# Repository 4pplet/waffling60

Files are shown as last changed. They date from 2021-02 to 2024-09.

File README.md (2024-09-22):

# waffling60

waffling60 is a multilayout 60% PCB with support for common ANSI and ISO layouts and split space. The PCB is split into different versions:
- ALPS tray mount version. Fit o-ring gummy worm if USB-port is not populated.
- MX tray mount version. Fit o-ring gummy worm if USB-port is not populated.
- MX Hot swap tray mount PCB in ISO layout. Fit o-ring gummy worm if USB-port is not populated.
- MX Hot swap tray mount PCB in ANSI layout. Fit o-ring gummy worm if USB-port is not populated.
- NMB Space Invader version. Fit o-ring gummy worm if USB-port is not populated.
- A dedicated version of the MX solder PCB to fit bakeneko/Kei cases. For use in Kei cases, a shorter or more flexible daughter board cable is recommended due to a slight different connector placement on PCB.
- A dedicated version of the MX solder PCB to fit ai03 Polaris V1.

Note: Waffling60 ISO HS Rev E is still being verified and added to QMK and VIA. At the moment, use revision D files for manufacturing. When tested and added, I'll change the releases from pre-release to release.

## Features:
- QMK & VIA
- USB-C
- RGB-led under to capslock-switch for non-hotswap and NMB versions. A transparent switch is needed to see the light from the LED through the switch.
- 16 underglow LEDs
- Cherry PCB-stab support
- Split space
- USB horizontal placement is classic GH60, same as GH60, plain60, voyager60 etc for the tray mount versions.
- SE-version is adapted for Polaris (stab-rotations, outline and USB-placement), make sure to order 1.2 mm thickness when manufacturing these.
- Rotary encoder support on top row, furthest to the right. Split backspace position. Only specific SMD encoders fit. Example further down.

## **Disclaimer/note:**
- **Important:** SE version of waffling60 (Polaris compatible version) are not officially endorsed by ai03 and ai03 takes no responsibility or offers any support for these if there is any issue. I have been given permission to open source and offer these for sale.**

## Availability:
As an option to DIY, I'll try and keep these available for purchase here: https://4pplet.com/ For DIY, the production files are avaliable in releases.

## Layout support MX: 
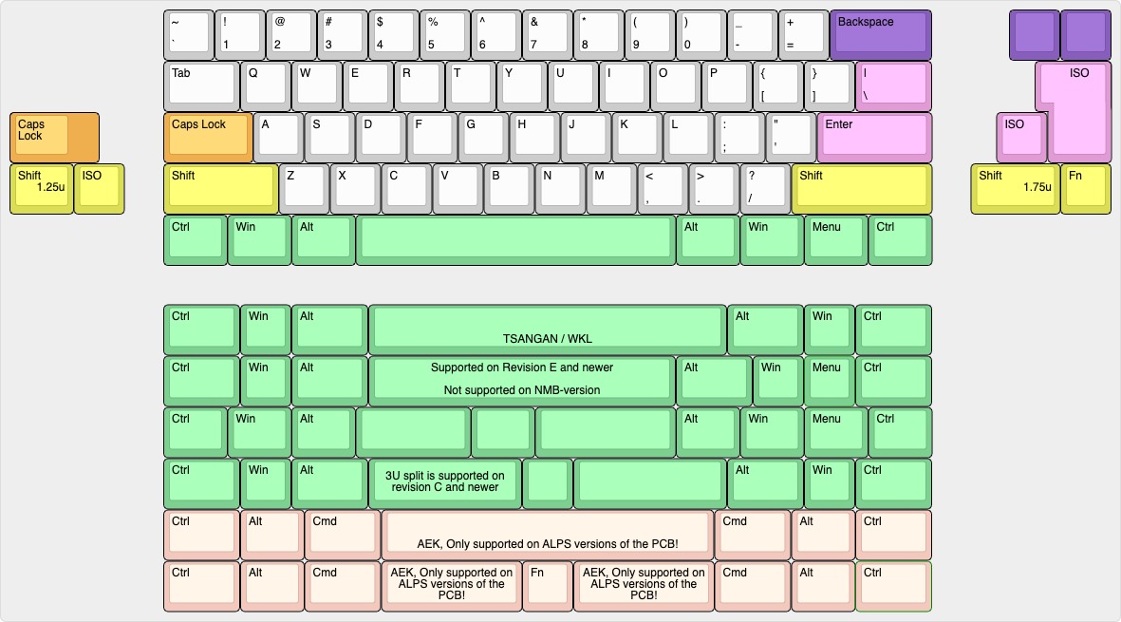
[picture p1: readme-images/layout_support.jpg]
Layout support


## MX Solder
PCB View - Rev E

## ALPS Solder
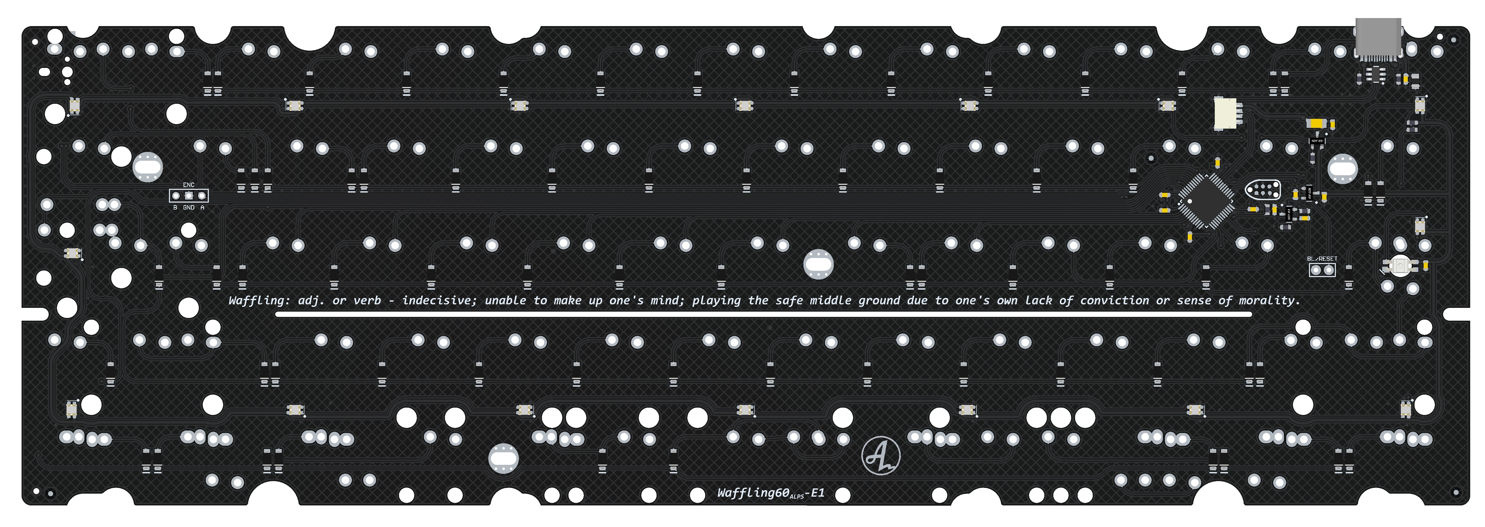
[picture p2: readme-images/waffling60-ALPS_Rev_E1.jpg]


## SE ("Bolaris")
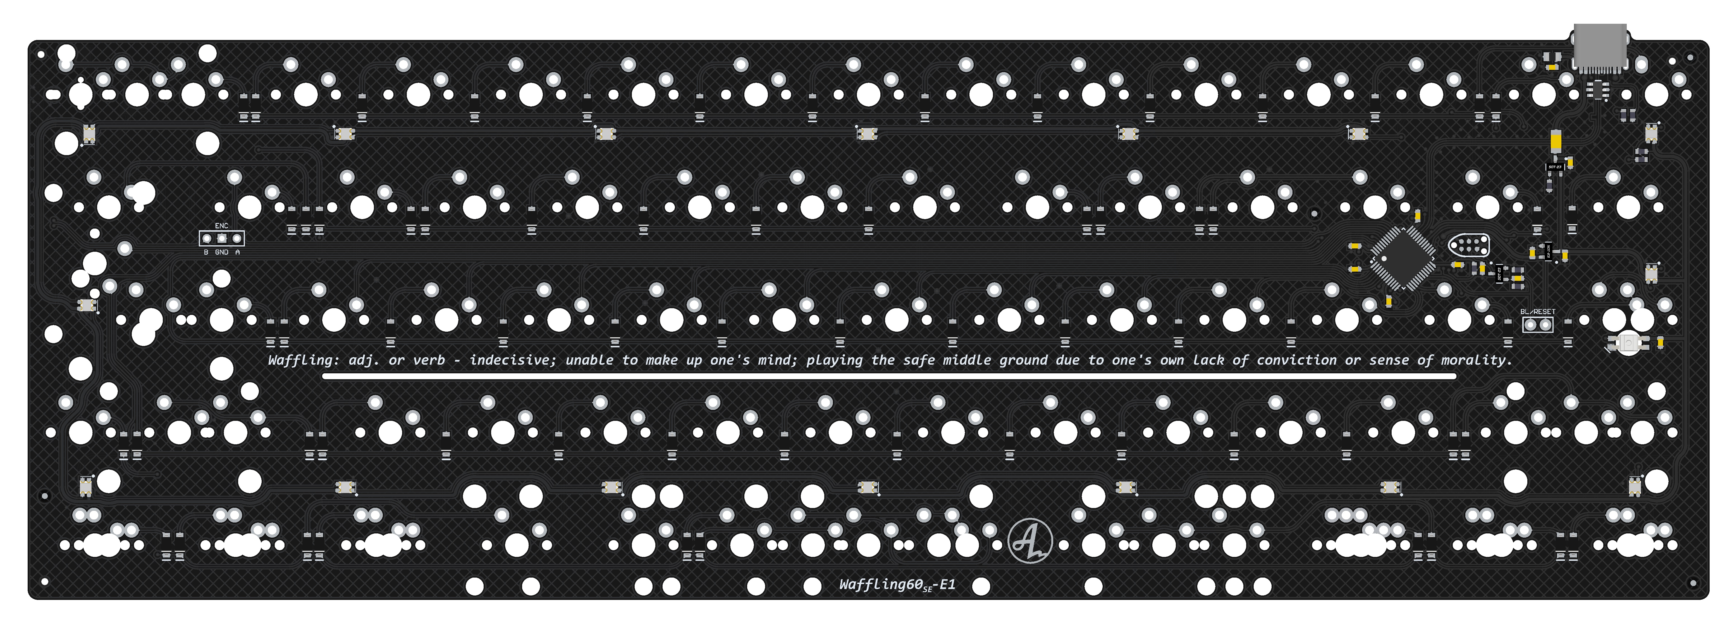
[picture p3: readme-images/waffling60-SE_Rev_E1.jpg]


## DB (Daughterboard/"Bakeneko")
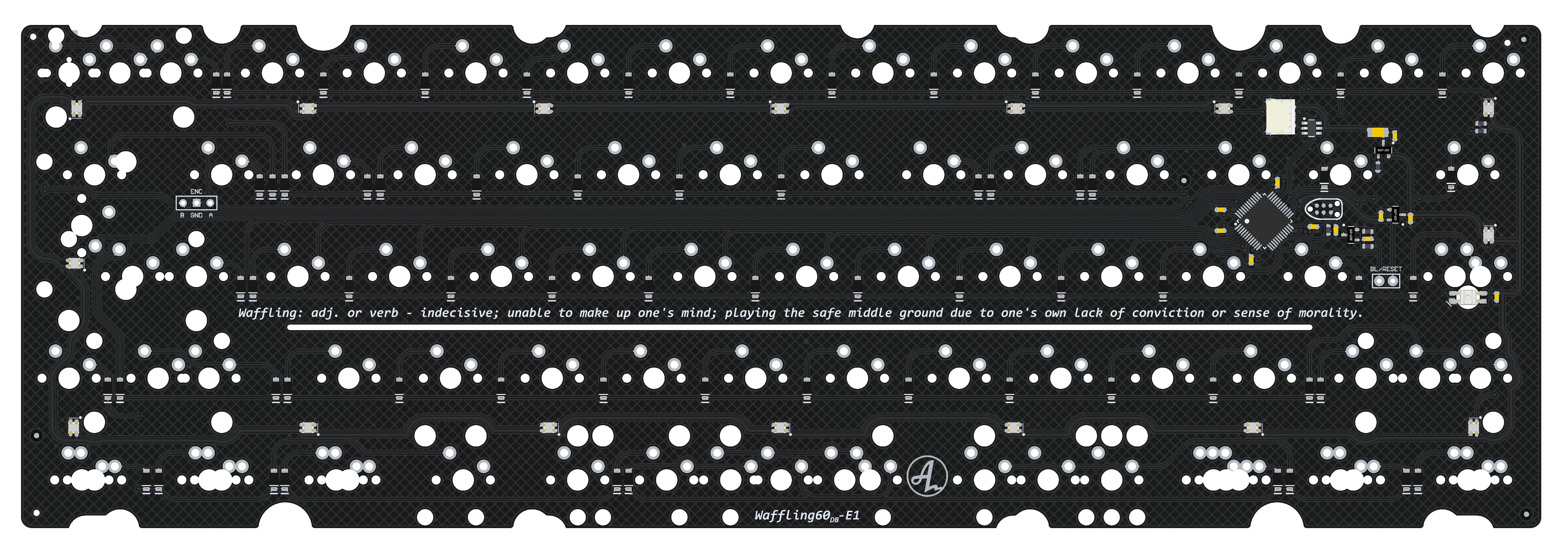
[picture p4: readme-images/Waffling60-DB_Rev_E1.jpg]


## NMB (NMB/Space Invaders)
PCB View - Rev E

## Layout support MX HS ISO: 
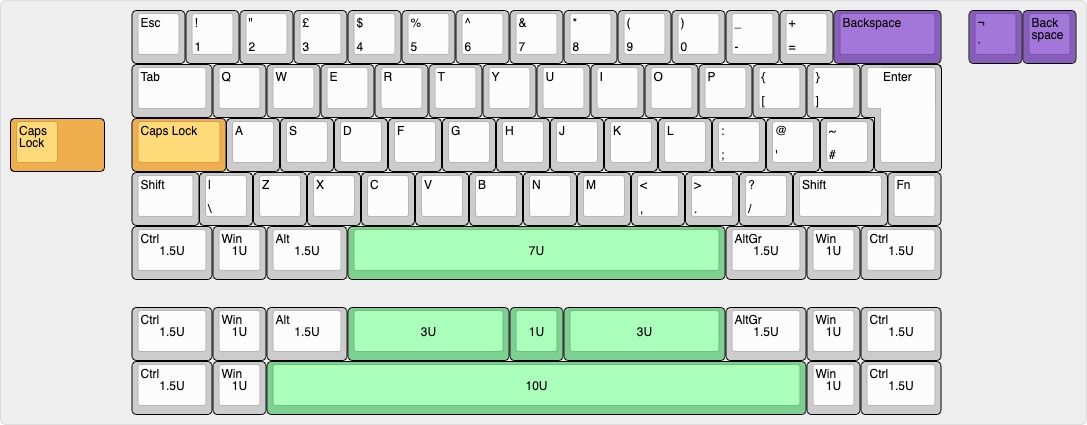
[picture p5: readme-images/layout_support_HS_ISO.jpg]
Layout support


## MX Hot Swap ISO
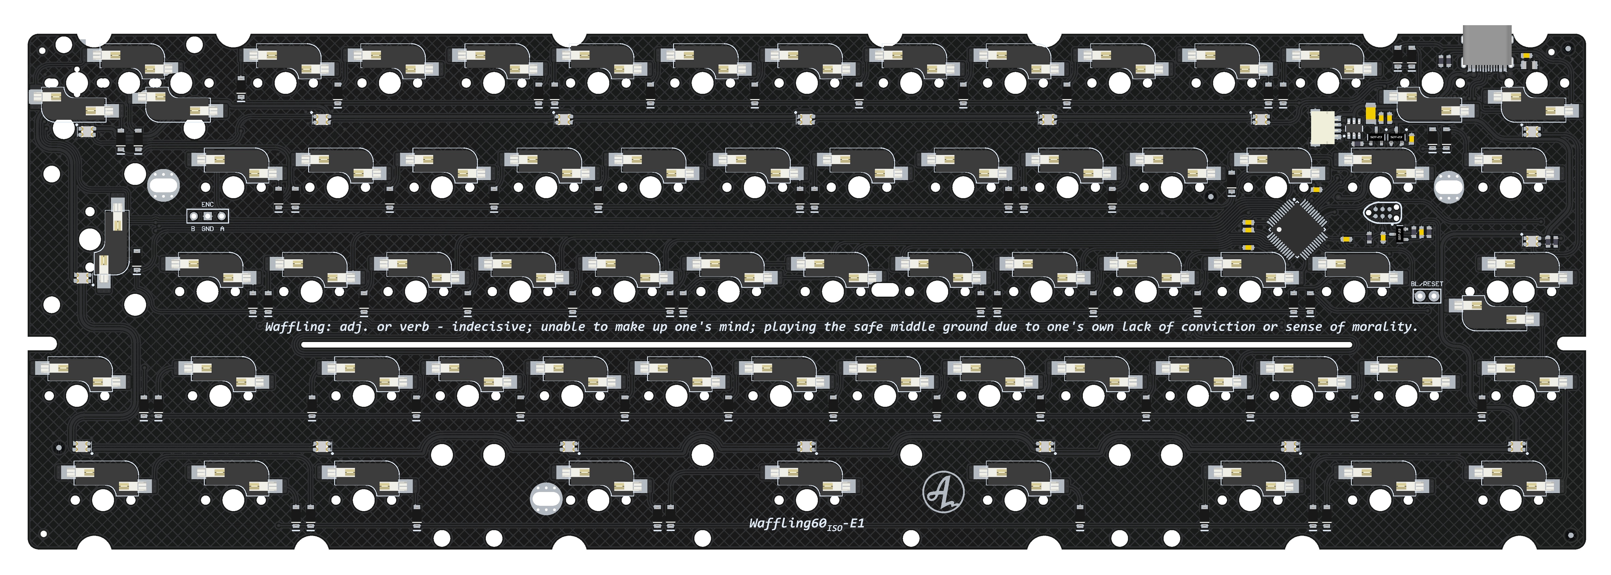
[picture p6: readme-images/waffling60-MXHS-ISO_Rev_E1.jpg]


## Layout support MX HS ANSI: 
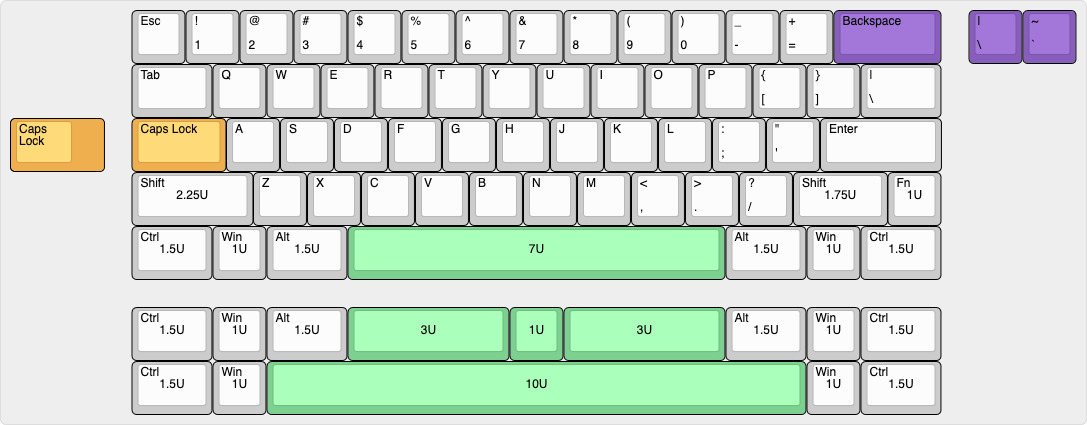
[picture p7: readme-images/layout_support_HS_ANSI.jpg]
Layout support


## MX Hot Swap ANSI
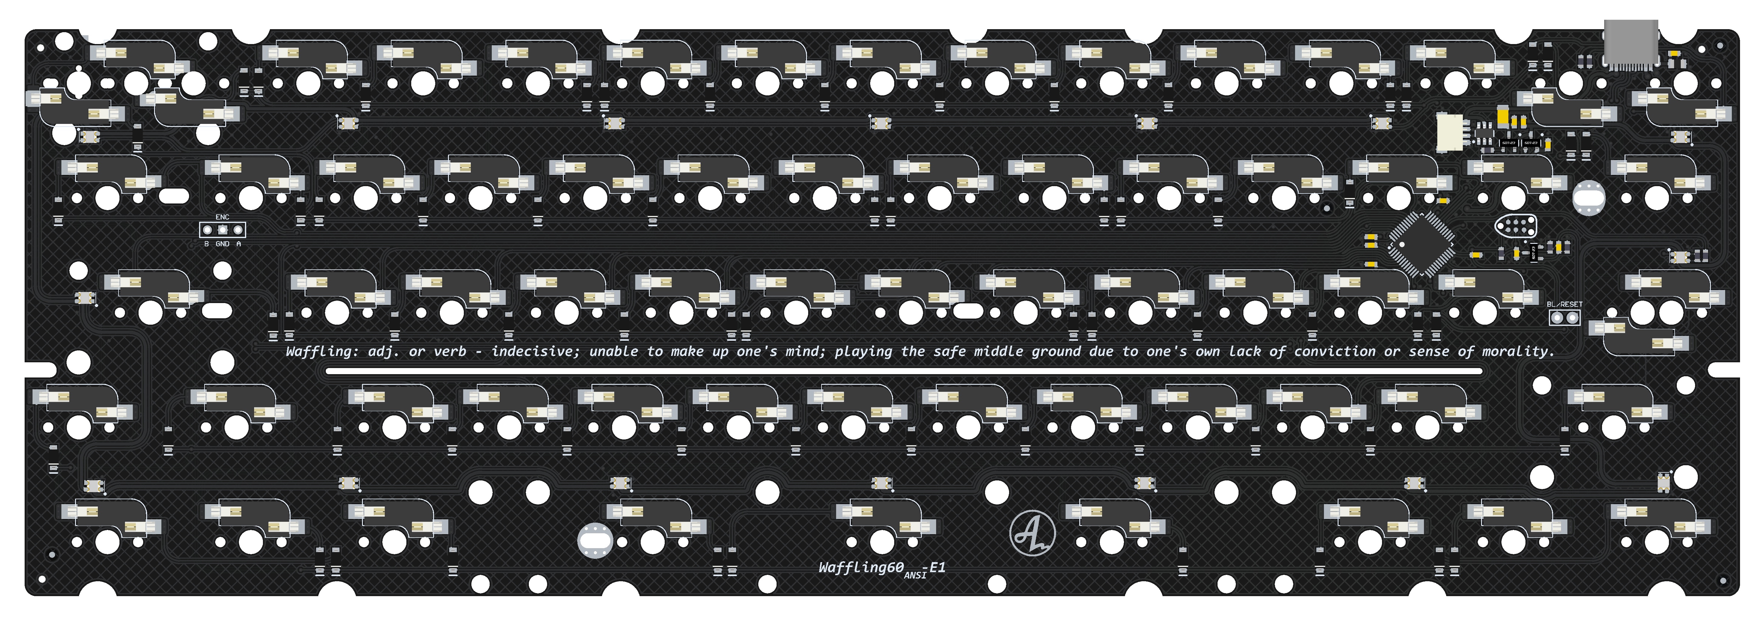
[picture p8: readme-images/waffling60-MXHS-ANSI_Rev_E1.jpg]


## Deviations on NMB version due to switch/footprint constraints:
- Different x-axis JST position, further from the PCB center.
- No Rotary encoder on PCB
- No 6U support
- Different encoder header position for off PCB encoder
- Different JTAG tagconnect position

## Instructions for manufacturing.
All PCBs except for the SE-version ("Bolaris") can be assembled for use with a bakeneko-style case. Simply remove the USB-port from the BOM or de-select it/tell the manu not to assemble it. The process will vary depending on what manufacturer is used.

## For ordering:
The following files are needed for the PCB Fab:
- BOM (contains component specifications)
- Pick and Place (contains component placement data)
- Gerber (contains PCB drawings and drill files)

## Releases
Files for manufacturing can be found in releases: https://github.com/4pplet/waffling60/releases

## Revision naming scheme
- Revision: When updating the PCB I bump the revision. The revision is specified with a letter and a number. For big changes, the letter is changed (usually also include code changes), for minor changes, only the number is bumped.
- Version: Version specifies different switch types, PCB's specific to certain cases etc.

## Revision history:
- Rev A1: Initial prototype based on Steezy60 Alps-version.
- Rev A2: Rotate Fn-switch (split RShift) on solder version. Rotate LShift stabilizer on both versions. To rotate left shift stabilizer on hot-swap pcb, adjacent sockets is also rotated.
- Rev B1: Changed matrix and diode under capslock for cleaner routing and easier software implementation in QMK for LED
- Rev B2: Moved daughter board connector to allign all projects with a similar horisontal position and a identical vertical position. Removed flex-cuts for more preictable feel in "traditional" cases.
- Rev B3: Changed stab rotation to what's more common today. Alligns with most common projects and cases. Updated PCB outline. Moved daughter board connector for better position in bakeneko. Added flexcuts again, but a simpler one.
- Rev B4: Changes to PCB outline, added support for bakeneko V3 and possibly KEI
- Rev B5 - Alps: Adding symetrical split space support using AEK-keycaps and adding RGB led below capslock switch for use with transparent switches (matias)
- Rev C1: Revision adds 3u+1U+3U Split space and 10U space support.
- Rev D: Moves to APM32 MCU, minor changes to routing and USB shielding.
- Rev E1: Adds NMB version. Adds underglow, rotary encoder support and 6u space support. Changed the switch rotation on MX ISO-enter. Reset button removed to reduce risk of resetting the board when bottoming out or when using a lot of foam.
- Rev E2: Fixes missing underglow resistor on NMB PCB. Fixes incorrect 6u support on solder PCBs (all versions with 6u support).
- Rev E3 on Waffling60SE: Adds a missing 5-pin switch hole on bottom row.
- Rev E3 on Waffling60DB: Adjusting UDB connector to align with the rest of the project. It had a slight offset.

## Encoders:
The footprint for encoders is a fairly common one. It supports two versions of bottom pins. The one below is an example. Similar looking SMD encoders (pin placement and bottom pins) will likely fit.

Example of tested encoders:

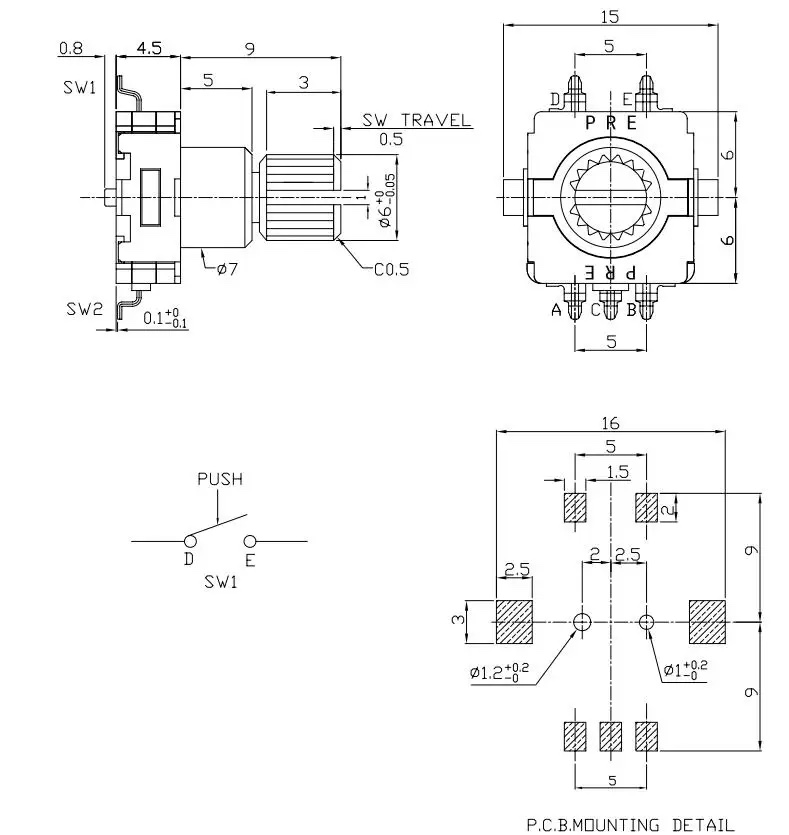
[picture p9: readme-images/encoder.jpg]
Aliexpress Encoder


Link: https://www.aliexpress.com/item/1005001265188249.html

<a href='https://ko-fi.com/4pplet' target='_blank'>Buy Me a Coffee at ko-fi.com

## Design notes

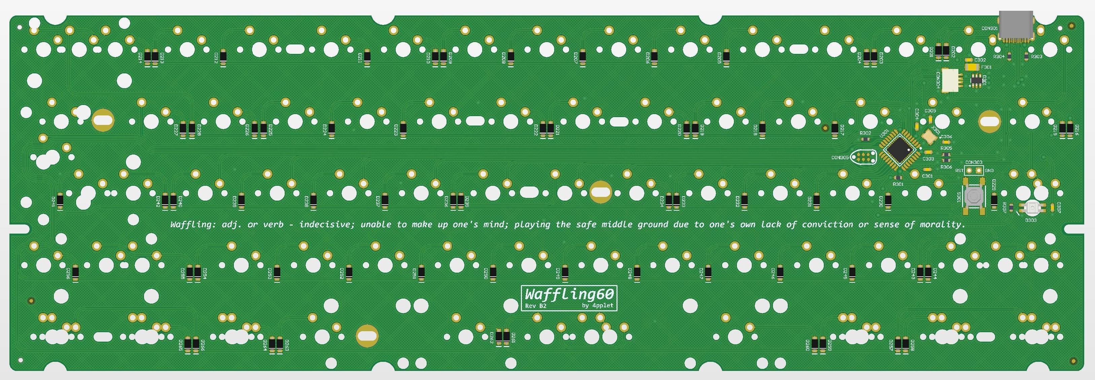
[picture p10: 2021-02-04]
readme-images/waffling60-MX_Rev_B2.jpg

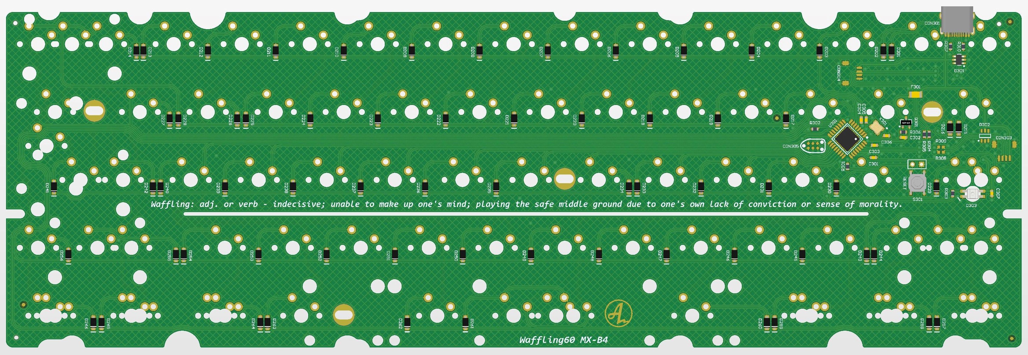
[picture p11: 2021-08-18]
readme-images/waffling60-MX_Rev_B4_Tray.jpg

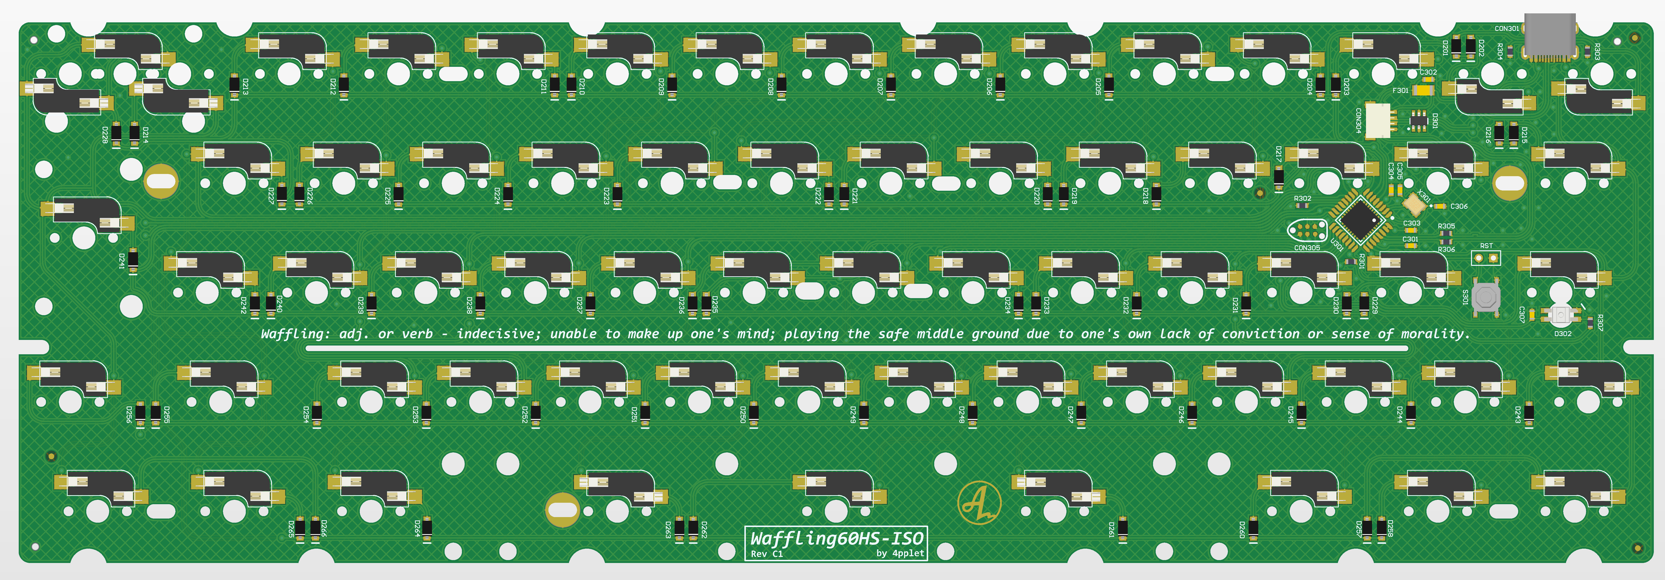
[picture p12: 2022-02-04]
readme-images/waffling60-MXHS_Rev_C1.png

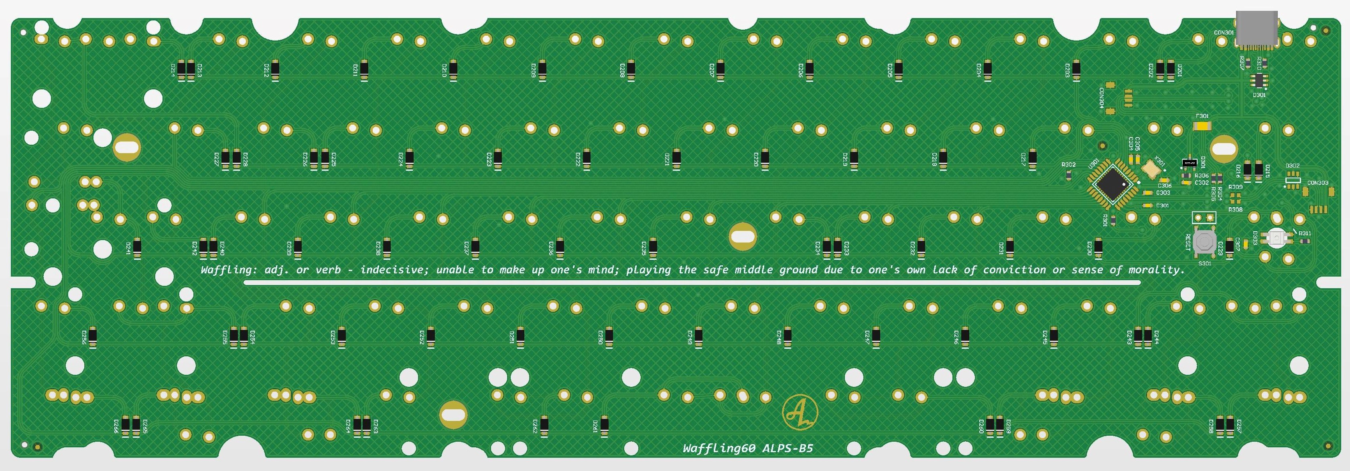
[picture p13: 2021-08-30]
readme-images/waffling60-ALPS_Rev_B5_Tray.jpg

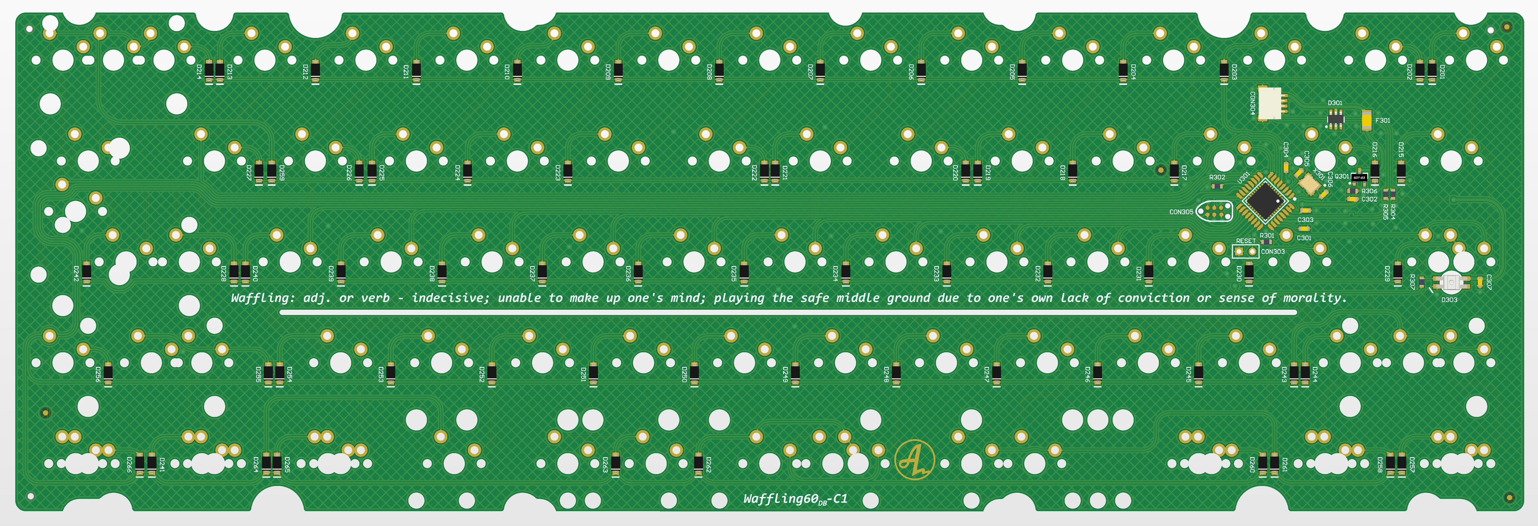
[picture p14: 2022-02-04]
readme-images/waffling60-DB_Rev_C1.png

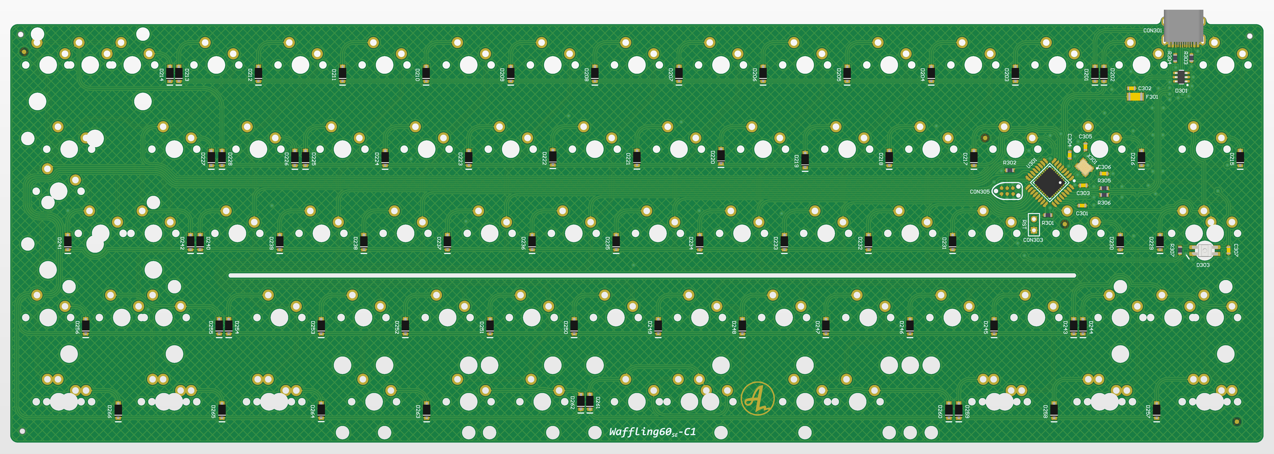
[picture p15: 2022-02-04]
readme-images/waffling60-SE_Rev_C1.png

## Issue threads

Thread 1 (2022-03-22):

Changing the Microcontroller

derUser19, 2022-03-22:
Are there any plans on using a different microcontroller since the ATMEGA32U2 has a shortage?

I'm new to this and tried to create a PCB but the ATMEGA32U2 is out of stock (apparently for the next months)

thanks for the info

4pplet, 2022-04-11:
Sorry for the delayed answer. I have been considering to maybe switch MCU to the RP2040 when QMK and ZMK ports are complete. The STM32 situation is not much better, so I'd not want to redesign the project to potentially have another MCU that's not in stock. Hopefully we will see the ATMEGA32U2 back in stock soon.

Closed 2022-04-11.

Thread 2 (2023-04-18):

ISO return switch should be rotated 90º

danbee, 2023-04-18:
Hi! This looks like a super interesting project. I'm really interested in building an ISO hotswap PCB but I just wanted to let you know that the switch for the return key needs to be rotated by 90 degrees.

4pplet, 2023-05-21:
Hi @danbee ! Thanks for showing interest in the project 👍

Afaik the current rotation is the more common one, it's what's generally used by Cherrys own keyboards.

danbee, 2023-05-26:
Hi @4pplet, I have several pre-built ISO boards, including a Cherry G80-3000 and the enter keyswitch is rotated 90 degrees in every case. Here's a few pictures I dug up off the Internet showing this. The first is a Cherry G80-3000 and the second is a WASD V3.

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

I've definitely seen both orientations, but I believe the 90 degree rotation is correct, as I have experienced very tight fitting keycaps on boards with the switch not rotated (specifically a DZ60) compared with boards with the switch rotated (E.g. a GH60).

Anyway, I hope you'll reconsider!

4pplet, 2023-05-26:
Hey @danbee !

I appreciate the detailed response, I'll for sure take it into consideration for future revisions 👍

4pplet, 2023-10-19:
Hey @danbee ! Just to let you know, the ISO enter rotation will be updated on the upcoming release (E). The design files are up, but all is not yet verified or supported in software (QMK + VIA).

Have a nice day!

danbee, 2023-10-19:
@4pplet That's awesome, thanks for letting me know!

Closed 2023-05-21.

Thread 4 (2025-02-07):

Hostswap Sockets Compatibility

TobiWan54, 2025-02-07:
I think it would be useful to state which types of hostswap socket are compatible with the HS PCBs. I assume it includes Kailh sockets and their clones, such as Gaterons?

4pplet, 2025-02-13:
The PCBs are designed for Kailh sockets which is specified in BOM. It should be compatible with Kailh clones, however the rotation instruction on silk is made for Kalih sockets, so it will look a bit off soldering Gaterons to the PCB, since they have a different shape.

I've not used many of the clone sockets, so I can't really speak on their compatibility for this project (it's not verified), but most MX-style sockets should work, just be aware of the rotation.

I'll add a note about this next time I update the readme! 👍

Closed 2025-02-13.

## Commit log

2020-01-18 Started working on it, no iso and ansi support at the same time
    Started working on it, no iso and ansi support at the same time. Need to be soldered as either
    [1_top.SchDoc, 2_matrix.SchDoc, 3_mcu.SchDoc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]
2020-01-18 right side mods done
    right side mods done
    [SteezyHS.PcbDoc]
2020-01-19 gave up on multi layout, semi-fixed
    gave up on multi layout, semi-fixed
    [2_matrix.SchDoc, SteezyHS.PcbDoc]
2020-01-19 testing 90 degree rotated switches
    testing 90 degree rotated switches, a lot easier to get more layout support
    [2_matrix.SchDoc, 3_mcu.SchDoc, SteezyHS.PrjPcb]
2020-01-21 Major changes in matrix to free up PWM pins
    Major changes in matrix to free up PWM pins. 7x10-matrix will be used.
    [1_top.SchDoc, 2_matrix.SchDoc, 3_mcu.SchDoc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]
2020-01-22 Connected matrix, removed underglow due to not enough pins
    Connected matrix, removed underglow due to not enough pins
    [1_top.SchDoc, 2_matrix.SchDoc, 3_mcu.SchDoc]
2020-01-22 lentgh tuned, updated out-file and removed underglow sheet
    lentgh tuned, updated out-file and removed underglow sheet
    [4_underglow.SchDoc]
2020-01-22 fixed some silkscreen issues, updated matrix with switched pol footprint
    fixed some silkscreen issues, updated matrix with switched pol footprint
    [1_top.SchDoc, 2_matrix.SchDoc, 3_mcu.SchDoc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]
2020-01-22 Seems to have been able to do without 90-degree rotation on switches
    Seems to have been able to do without 90-degree rotation on switches
    [2_matrix.SchDoc, 3_mcu.SchDoc]
2020-01-22 Added stuff to todo and added info in silk
    Added stuff to todo and added info in silk
    [SteezyHS.PrjPcb]
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2020-01-25 rotated switches 90 degree again to fit ISO enter stabilizers
    rotated switches 90 degree again to fit ISO enter stabilizers. Stared doing a FR4-plate
    [3_mcu.SchDoc, SteezyHS.PrjPcb]
2020-01-26 Fixed plate and moved reset switch to fit plate better
    Fixed plate and moved reset switch to fit plate better
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2020-01-30 Added BOM on silk, lined up diodes better
    Added BOM on silk, lined up diodes better
    [2_matrix.SchDoc, 3_mcu.SchDoc]
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2020-01-31 Added non-hotswap version, fixed project structure with new names
    Added non-hotswap version, fixed project structure with new names
    [1_top.SchDoc, 1_waffling60-MXHS_top.SchDoc, 1_waffling60-MX_top.SchDoc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]
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2020-02-03 Fixed dp/dn-switch
    Fixed dp/dn-switch
    [3_waffling60-MXHS_mcu.SchDoc, 3_waffling60-MX_mcu.SchDoc, waffling60-MXHS.PrjPcb]
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2020-02-04 Files ready for initial prototype
    Files ready for initial prototype
    [2_waffling60-MX_matrix.SchDoc, waffling60-MX.PrjPcb, waffling60_plate.PcbDoc]
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2020-02-05 Rotated stabilizers on solder-version for better plate compatibility
    Rotated stabilizers on solder-version for better plate compatibility (universal plates)
    [waffling60-MX.PrjPcb]
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2020-02-06 Restored ansi-enter rotation, now like DZ60 and other common PCB's
    Restored ansi-enter rotation, now like DZ60 and other common PCB's. Modified plate, hopefully will be accepted by JLCPCB
    [waffling60_plate.PcbDoc]
2020-02-06 Updated plate for use with rotated shift-stab (rev A2)
    Updated plate for use with rotated shift-stab (rev A2)
    [waffling60_plate.PcbDoc]
2020-02-07 added pad on some mounting holes
    added pad on some mounting holes
    [waffling60_plate.PcbDoc]
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2020-02-14 added schematic, updated footprint for diode on solder pcb
    added schematic, updated footprint for diode on solder pcb
    [waffling60-MX.PrjPcb]
2020-02-14 updated color on jst connector
    updated color on jst connector
    [waffling60-MX.PrjPcb, waffling60-MXHS.PrjPcb]
2020-02-14 fixed name on schematic
    fixed name on schematic
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2020-02-22 Fixed rotated switch, rotated diodes so all face the same way (again)
    Fixed rotated switch, rotated diodes so all face the same way (again)
2020-02-24 Fixed incorrect resistor number on silk
    Fixed incorrect resistor number on silk
    [2_waffling60-MX_matrix.SchDoc, 3_waffling60-MXHS_mcu.SchDoc, 3_waffling60-MX_mcu.SchDoc]
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2020-02-25 made matrix schematic look nicer on HS
    made matrix schematic look nicer on HS
    [1_waffling60-MXHS_top.SchDoc, 1_waffling60-MX_top.SchDoc, 2_waffling60-MXHS_matrix.SchDoc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]
2020-03-08 Updated to combo reset switch footprint
    Updated to combo reset switch footprint
    [3_waffling60-MXHS_mcu.SchDoc, 3_waffling60-MX_mcu.SchDoc]
2020-03-08 added items to BOM
    added items to BOM
    [3_waffling60-MXHS_mcu.SchDoc, 3_waffling60-MX_mcu.SchDoc]
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2020-03-17 fixed BOM-generation, updated RGB-led silk
    fixed BOM-generation, updated RGB-led silk
    [3_waffling60-MXHS_mcu.SchDoc, 3_waffling60-MX_mcu.SchDoc]
2020-03-17 fixed issue with schematic generation
    fixed issue with schematic generation
    [1_waffling60-MXHS_top.SchDoc, 1_waffling60-MX_top.SchDoc, 3_waffling60-MX_mcu.SchDoc]
2020-03-17 fixed schematic
    fixed schematic, port names not showing
2020-03-19 switched polarity on some multi layout footprints for lower risk of solder error
    switched polarity on some multi layout footprints for lower risk of solder error
2020-03-19 fixed backspace switch polarity for less risk of solder issue
    fixed backspace switch polarity for less risk of solder issue
2020-03-25 added tenting on switch-pads on top for better astetics
    added tenting on switch-pads on top for better astetics
    [2_waffling60-MX_matrix.SchDoc]
2020-03-30 removed pad-opening in top-solder for switches, moved usb-connector out a bit
    removed pad-opening in top-solder for switches, moved usb-connector out a bit
    [waffling60_plate.PcbDoc]
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2020-04-22 restored previous flex cut solution
    [3_waffling60-MXHS_mcu.SchDoc, 3_waffling60-MX_mcu.SchDoc]
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2020-04-23 updated for JLC assembly
    updated for JLC assembly
    [2_waffling60-MXHS_matrix.SchDoc, 2_waffling60-MX_matrix.SchDoc, 3_waffling60-MXHS_mcu.SchDoc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]
2020-06-07 updated plate with missing iso switch
    updated plate with missing iso switch
    [waffling60-MXHS.PrjPcb, waffling60_plate.PcbDoc]
2020-06-07 updated outfile to export plate layers correctly
    updated outfile to export plate layers correctly
2020-06-07 updated readme with fixed plate
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2020-07-02 added posibility of solder reset switch under space
    [3_waffling60-MX_mcu.SchDoc]
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2020-08-14 fixing with HS-version
    [1_waffling60-MXHS_top.SchDoc, 2_waffling60-MXHS_matrix.SchDoc, 3_waffling60-MXHS_mcu.SchDoc]
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2020-09-15 fixed 6.25u spacebar
    [waffling60-MX.PcbDoc, waffling60-MXHS.PcbDoc]
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2021-01-19 moving DBC connector to allign with other projects
    moving DBC connector to allign with other projects
    [waffling60-MX.PrjPcb, waffling60-MXHS.PrjPcb]
2021-01-26 started modifying plate with tighter tolerances for outline (-1mm)
    started modifying plate with tighter tolerances for outline (-1mm)
    [waffling60-MXHS.PrjPcb, waffling60_plate.PcbDoc]
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2021-05-09 updated with the same ansi enter stabilizer rotation as bakeneko
    updated with the same ansi enter stabilizer rotation as bakeneko
    [waffling60-BK.PcbDoc]
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2021-06-29 added PDF output for the different assembly options
    added PDF output for the different assembly options
    [waffling60-MX.PrjPcb]
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2022-01-11 fixed offset diode trace
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2022-09-21 fixed old partnr for 1206 1uF cap
    [3_waffling60-ALPS_mcu.SchDoc, 3_waffling60-MX_mcu.SchDoc, waffling60-MX.PrjPcb]
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2023-10-08 Squashed commit of the following:
    commit 6543ccd9e50567fed27906cb78979d124b5a2693
    Author: 4pplet <mail@4pplet.com>
    Date: Sun Oct 8 21:42:54 2023 +0200
    cont
    commit 593b75c4dd105e202ba4a9efa313c79a8bdf01b7
    Author: 4pplet <mail@4pplet.com>
    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
    [1_waffling60-ALPS_top.SchDoc, 1_waffling60-DB_top.SchDoc, 1_waffling60-MXHS-ANSI_top.SchDoc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]
2024-04-08 update readme with correct text on left shift in KLE for ANSI PCB
    update readme with correct text on left shift in KLE for ANSI PCB
2024-04-18 Squashed commit of the following:
    commit 98af7d52fa224d9cd0dbe26da3b5fc2c1ddef0ba
    Date: Wed Mar 27 14:40:09 2024 +0100
    adding missing resistors for underglow
    commit 0ec0fe8764192c518a5c1e260184d5645d3f9157
    Date: Thu Mar 21 17:15:21 2024 +0100
    Update Waffling60-NMB.PrjPcb
    commit e16e73e4bf263de04b64a6ab5167c7bf40bce637
    Date: Thu Mar 21 17:15:07 2024 +0100
    add underglow pullups to NMB PCB
    commit a4a88823ff0d599f15eb4eff3042a949a74de827
    Date: Sun Feb 4 22:49:30 2024 +0100
    commit 1a46759b3ac1731a7c5ae6cfdb0198d49b748850
    Author: 4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
    [2_waffling60-ALPS_matrix.SchDoc, 2_waffling60-DB_matrix.SchDoc, 2_waffling60-MX_matrix.SchDoc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]
2024-06-14 adding missing alignment pin hole on bottom row for 5-pin switches.
    [1_waffling60-SE_top.SchDoc, waffling60-SE.PrjPcb]
2024-06-15 Adjust UDB position
    Adjust UDB position slightly to align with the rest of the project
    [3_waffling60-DB_mcu.SchDoc, waffling60-DB.PrjPcb]
2024-10-25 Fixed error in rotation-marking for MCU
    [1_waffling60-MXHS-ISO_top.SchDoc, 3_waffling60-MXHS-ISO_mcu.SchDoc, 4_waffling60-MXHS-ISO_periferals.SchDoc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]
